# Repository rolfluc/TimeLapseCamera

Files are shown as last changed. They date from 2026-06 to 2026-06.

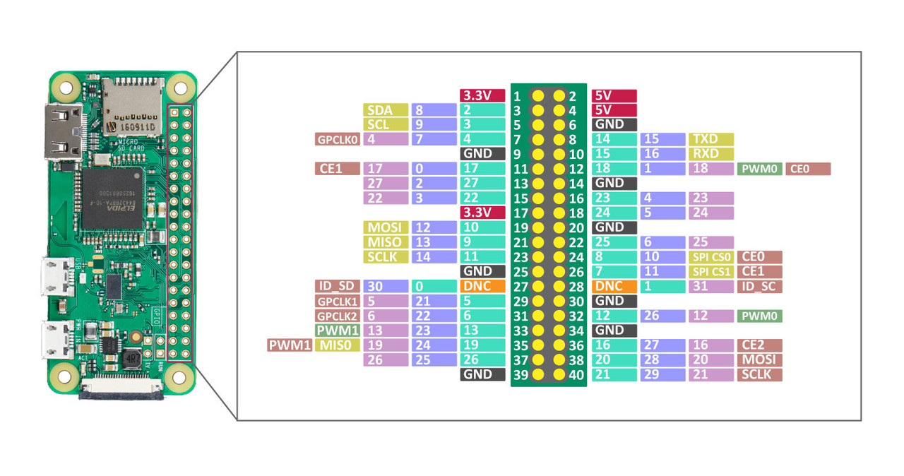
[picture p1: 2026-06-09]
Electrical/Pinout.png

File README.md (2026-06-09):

# TimeLapseCamera
Repo Housing the Mechanical, Electrical, Tests, and Software / layer config for taking an RPI Zero 2W into a time lapse / mobile camera for a rechargable battery.
The following steps are to setup yocto for building an RPI image for the RPI Zero W2
```
git clone -b scarthgap https://git.yoctoproject.org/poky
```
```
git clone -b scarthgap https://git.yoctoproject.org/meta-raspberrypi
```
```
source poky/oe-init-build-env build-rpi
```
```
bitbake-layers add-layer ../meta-raspberrypi
```
-> Confirm layer was added to conf/bblayers.conf

```
set local.conf -> 'MACHINE ??=' -> 'MACHINE = "raspberrypi0-2w-64"' 
```
^-- this matches ~/yocto-rpi/meta-raspberrypi/conf/machine/
```
set local.conf -> IMAGE_FSTYPES = "wic.bz2"
set local.conf -> LICENSE_FLAGS_ACCEPTED = "synaptics-killswitch"
```
```
cd ~/yocto-rpi/build-rpi
```
```
bitbake core-image-base
```

Once Complete, check in : ~/yocto-rpi/build-rpi/tmp/deploy/images/raspberrypi0-2w-64/
for a file:
core-image-base-raspberrypi0-2w-64.rootfs.wic.bz2

In this case, WSL is being used to build, so RPI Imager is used to flash to an SD card.

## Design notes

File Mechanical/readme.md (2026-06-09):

3D Printed files found at :
https://www.printables.com/model/988094-raspberry-pi-zero-2-w/files
Not checked in here since very large files

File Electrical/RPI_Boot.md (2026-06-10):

Boot Status Table. This is determined by whether the device boots, and the login prompt is selected.

| Voltage 	| Status| Power on Boot 	|
| 5.0 V 	| ✅ 	|	0.689W			|
| 4.7 V 	| ✅ 	|	0.670W			|
| 4.4 V 	| ✅ 	|	0.650W			|
| 4.1 V 	| ✅ 	|	0.635W			|
| 3.8 V 	| ✅ 	|	0.622W			|
| 3.7 V 	| ✅ 	|	0.615W			|
| 3.6 V 	| ✅ 	|	0.611W			|
| 3.5 V 	| ✅ 	|	0.604W			|
| 3.4 V 	| ✅ 	|	0.610W			|
| 3.3 V 	| ✅ 	|	0.603W			|
| 3.2 V 	| ✅ 	|	0.590W			|
| 3.1 V 	| ✅ 	|	0.590W			|
| 3.0 V 	| ✅ 	|	0.580W			|
| 2.9 V 	| ✅ 	|	0.570W			|

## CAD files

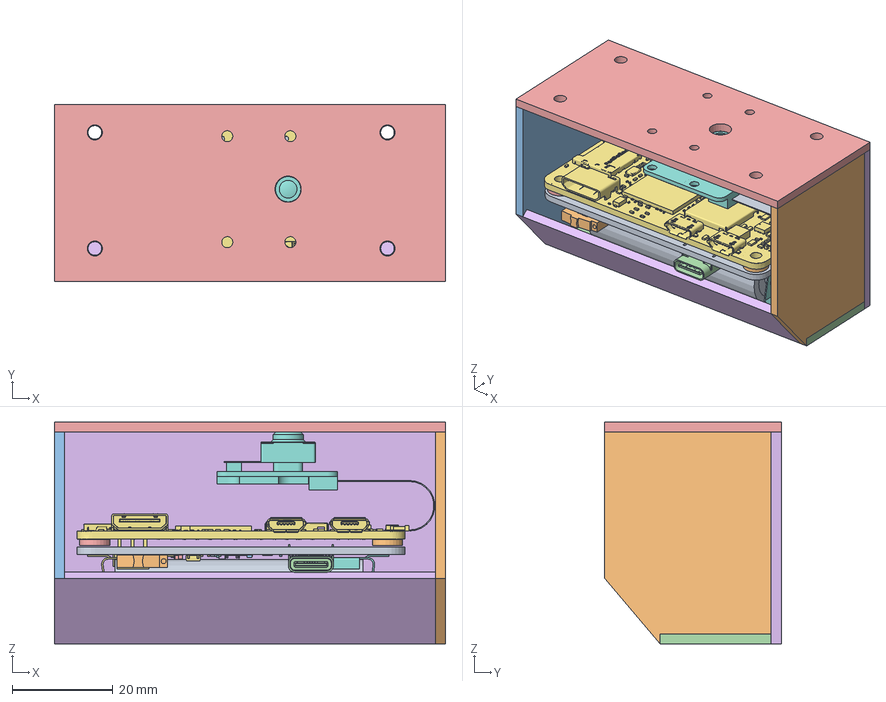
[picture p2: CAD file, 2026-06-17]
Mechanical/Housing.FCStd
77.5 x 35.0 x 44.0 mm
FlexCable
Tube
Tube001
Tube002
Tube003
SC-74A-5_1.55x2.9mm_P0.95mm
C_0402_1005Metric
R_0402_1005Metric
R_0402_1005Metric001
R_0402_1005Metric002
C_0402_1005Metric001
C_0603_1608Metric
TSOT-23-5
R_0402_1005Metric003
R_0402_1005Metric004
R_0402_1005Metric005
R_0603_1608Metric
R_0402_1005Metric006
USB_C_Receptacle_GCT_USB4085
C_0402_1005Metric002
C_0402_1005Metric003
BK-53
BK-054
EGJ1210AAG2
C_0402_1005Metric004
R_0402_1005Metric007
SOT-363_SC-70-6
WSON-6-1EP_2x2mm_P0.65mm_EP1x1.6mm
PinHeader_2x03_P2.54mm_Vertical
PowerAndControl_silkscreen
PowerAndControl_PCB
raspberry pi zero 2 w
Pi Camera Module v3

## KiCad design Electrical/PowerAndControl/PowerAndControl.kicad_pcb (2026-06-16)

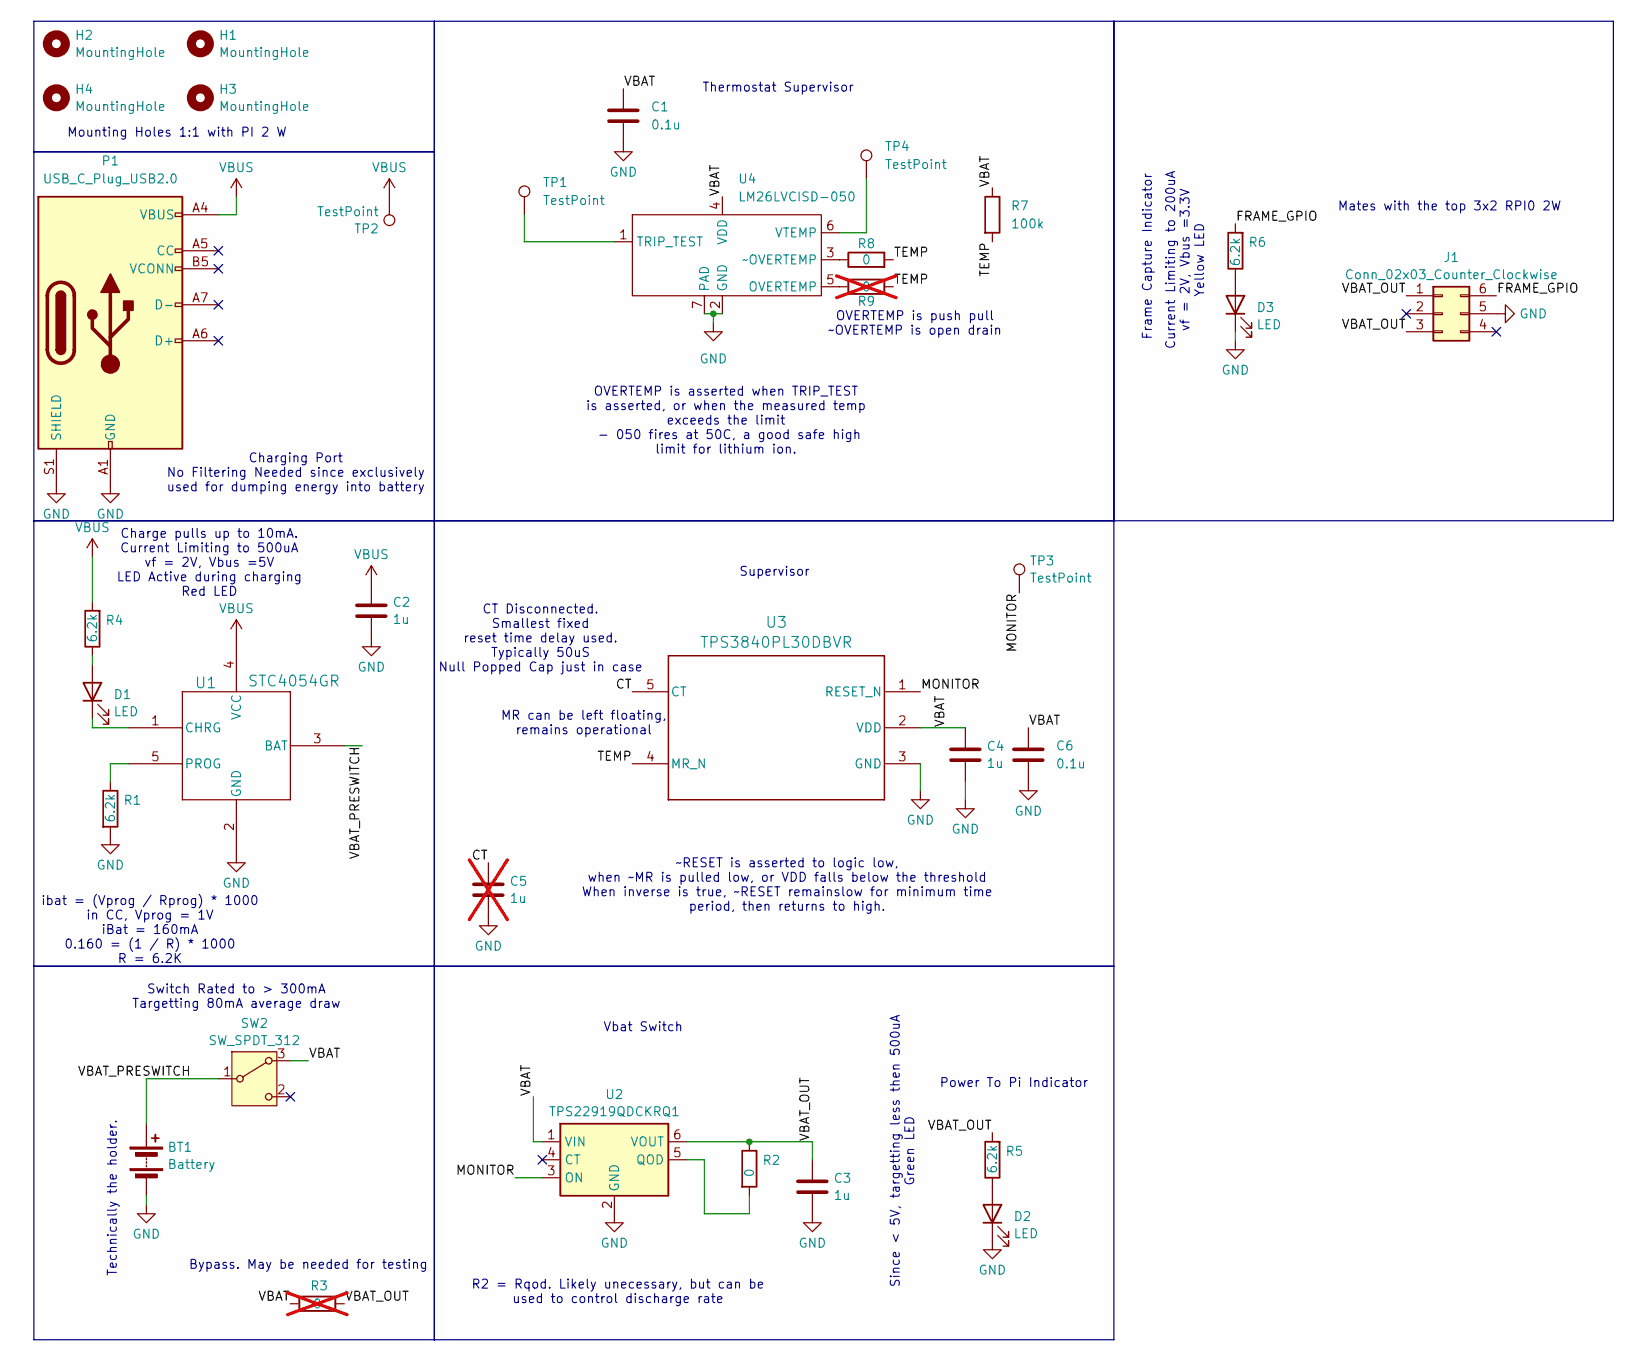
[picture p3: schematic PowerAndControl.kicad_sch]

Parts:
BT1: Battery; BAT_BK-53; MPN BAT_BK-53
C1, C6: 0.1u; C_0402_1005Metric_Pad0.74x0.62mm_HandSolder
C2, C3, C4: 1u; C_0402_1005Metric_Pad0.74x0.62mm_HandSolder; MPN CL05A105KO5NNNC
C5: 1u; C_0603_1608Metric_Pad1.08x0.95mm_HandSolder; not fitted
D1: LED; LED_0604; MPN LTST-S271KRKT
D2: LED; LED_0604; MPN LTST-S271KGKT
D3: LED; LED_0604; MPN LTST-S271KSKT
H1, H2, H3, H4: MountingHole; MountingHole_2.7mm_M2.5
J1: Conn_02x03_Counter_Clockwise; PinHeader_2x03_P2.54mm_Vertical
P1: USB_C_Plug_USB2.0; USB_C_Receptacle_GCT_USB4085
R1, R4, R5, R6: 6.2k; R_0402_1005Metric_Pad0.72x0.64mm_HandSolder
R2, R8: 0; R_0402_1005Metric_Pad0.72x0.64mm_HandSolder
R3: 0; R_0603_1608Metric_Pad0.98x0.95mm_HandSolder; not fitted
R7: 100k; R_0402_1005Metric_Pad0.72x0.64mm_HandSolder
R9: 0; R_0402_1005Metric_Pad0.72x0.64mm_HandSolder; not fitted
SW2: SW_SPDT_312; EGJ1210; MPN EGJ1210
TP1, TP2, TP3, TP4: TestPoint; TestPoint_Pad_1.0x1.0mm
U1: STC4054GR; TSOT-23-5_HandSoldering
U2: TPS22919QDCKRQ1; SOT-363_SC-70-6
U3: TPS3840PL30DBVR; SC-74A-5_1.55x2.9mm_P0.95mm
U4: LM26LVCISD-050; WSON-6-1EP_2x2mm_P0.65mm_EP1x1.6mm_ThermalVias

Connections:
/CT: C5.1, U3.5 (CT)
/FRAME_GPIO: J1.6, R6.2
/MONITOR: TP3.1, U2.3 (ON), U3.1 (RESET_N)
/TEMP: R7.2, R8.2, R9.2, U3.4 (MR_N)
/VBAT: C1.1, C4.1, C6.1, R3.1, R7.1, SW2.3 (A), U2.1 (VIN), U3.2 (VDD), U4.4 (VDD)
/VBAT_OUT: C3.1, J1.1, J1.3, R2.1, R3.2, R5.2, U2.6 (VOUT)
/VBAT_PRESWITCH: BT1.1 (+), SW2.1 (B), U1.3 (BAT)
GND: BT1.2 (-), C1.2, C2.2, C3.2, C4.2, C5.2, C6.2, D2.1 (K), D3.1 (K), J1.5, P1.A1 (GND), P1.A12 (GND), P1.B1 (GND), P1.B12 (GND), P1.S1 (SHIELD), R1.2, U1.2 (GND), U2.2 (GND), U3.3 (GND), U4.2 (GND), U4.7 (PAD)
unnamed: D1.2 (A), R4.1
unnamed: D1.1 (K), U1.1 (CHRG)
unnamed: D2.2 (A), R5.1
unnamed: D3.2 (A), R6.1
unnamed: R1.1, U1.5 (PROG)
unnamed: R2.2, U2.5 (QOD)
unnamed: R9.1, U4.5 (OVERTEMP)
unnamed: TP1.1, U4.1 (TRIP_TEST)
unnamed: TP4.1, U4.6 (VTEMP)
unnamed: R8.1, U4.3 (~OVERTEMP)
VBUS: C2.1, P1.A4 (VBUS), P1.A9 (VBUS), P1.B4 (VBUS), P1.B9 (VBUS), R4.2, TP2.1, U1.4 (VCC)

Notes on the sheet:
Technically the holder.
OVERTEMP is push pull ~OVERTEMP is open drain
Mounting Holes 1:1 with PI 2 W
Thermostat Supervisor
OVERTEMP is asserted when TRIP_TEST is asserted, or when the measured temp exceeds the limit - 050 fires at 50C, a good safe high limit for lithium ion.
Supervisor
Mates with the top 3x2 RPI0 2W
Power To Pi Indicator
CT Disconnected. Smallest fixed reset time delay used. Typically 50uS Null Popped Cap just in case
MR can be left floating, remains operational
~RESET is asserted to logic low, when ~MR is pulled low, or VDD falls below the threshold When inverse is true, ~RESET remainslow for minimum time period, then returns to high.
Charge pulls up to 10mA. Current Limiting to 500uA vf = 2V, Vbus =5V LED Active during charging Red LED
Switch Rated to > 300mA Targetting 80mA average draw
R2 = Rqod. Likely unecessary, but can be used to control discharge rate
ibat = (Vprog / Rprog) * 1000 in CC, Vprog = 1V iBat = 160mA 0.160 = (1 / R) * 1000 R = 6.2K
Current Limiting to 200uA vf = 2V, Vbus =3.3V Yellow LED
Bypass. May be needed for testing
Vbat Switch
Since < 5V, targetting less then 500uA Green LED
Frame Capture Indicator
Charging Port No Filtering Needed since exclusively used for dumping energy into battery

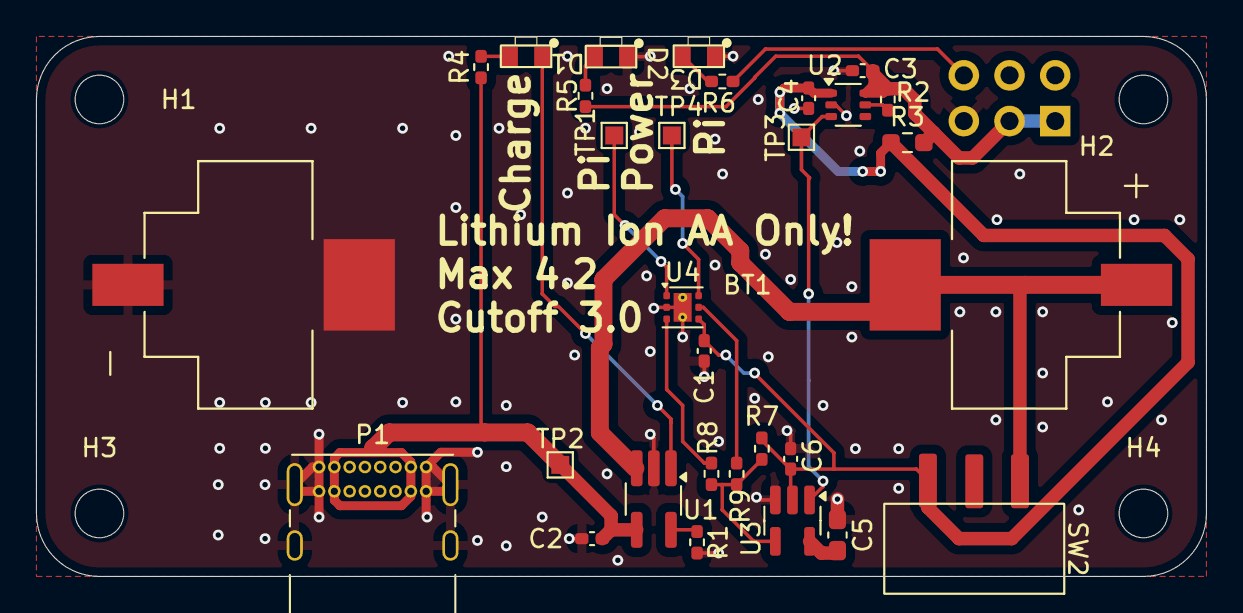
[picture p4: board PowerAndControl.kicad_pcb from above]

Board: 2 copper layers, 65.0 x 30.0 mm, 34 parts (1 on the bottom side), 19 nets.

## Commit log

2026-06-09 Starting Mechanical
    [Housing.FCStd]
2026-06-10 First pass Electrical
    Has Schematic.
    Has Outline,
    [PowerAndControl.kicad_pcb, PowerAndControl.kicad_sch]
2026-06-10 Layout of AA variant complete. Need to check pinout 2x more
    [PowerAndControl.kicad_pcb, PowerAndControl.kicad_sch]
2026-06-11 Cleaner Schematic / LED Indicators, better Layout
    Added 3 LEDs for indicators.
    Shcematic Cleaned up in general.
    New Charger component
    [PowerAndControl.kicad_pcb, PowerAndControl.kicad_sch]
2026-06-12 WIP Layout
    [Housing.FCStd]
2026-06-12 Cleared a TODO
    [PowerAndControl.kicad_pcb]
2026-06-12 Rough Positioning of Camera Module, with Cable.
    [Housing.FCStd]
2026-06-12 Added additional Silkscreen
    [PowerAndControl.kicad_pcb]
2026-06-15 WIP - added additionalCutouts
    [Housing.FCStd]
2026-06-15 Rerouted Switch, Added Thermostat
    Switch is now on the same side as the USB port. Should help
    reduce z axis stackup.
    Added thermostat, will shutoff if high temp
    [PowerAndControl.kicad_pcb, PowerAndControl.kicad_sch]
2026-06-16 Fixed up / Repositioned Model
    [PowerAndControl.kicad_pcb, PowerAndControl.kicad_sch]
2026-06-16 Fixed Minor Issue. Getting Fabbed
    [PowerAndControl.kicad_pcb]
2026-06-17 First Pass Housing
    [Housing.FCStd]
2026-06-18 Starting some Integration, current down to 100mA
